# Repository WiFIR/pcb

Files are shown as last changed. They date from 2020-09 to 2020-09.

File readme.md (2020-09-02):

# WiFI*R*

The WiFI*R* is a WiFi IR blaster / remote, based around a WeMos D1 mini (ESP8266)

The WiFIR was made from a need to control a heatpump / ac to allow pre-heating of a summer-house before arriving. It can however control anything IR controlled.

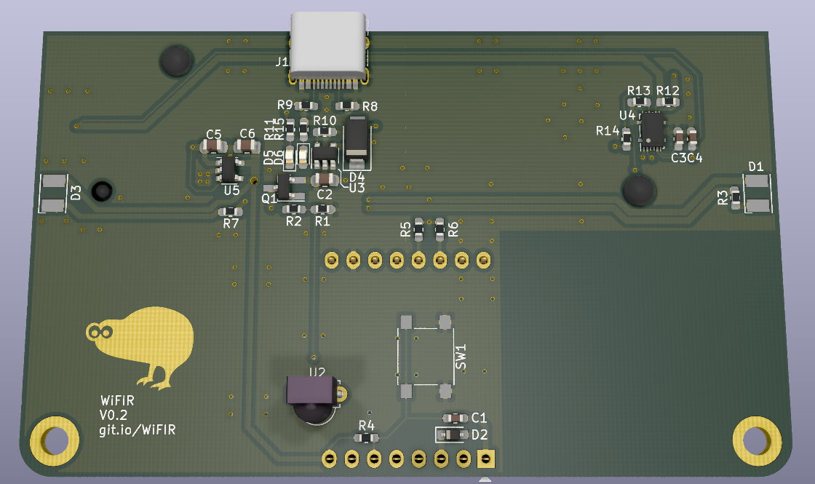
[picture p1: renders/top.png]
top render

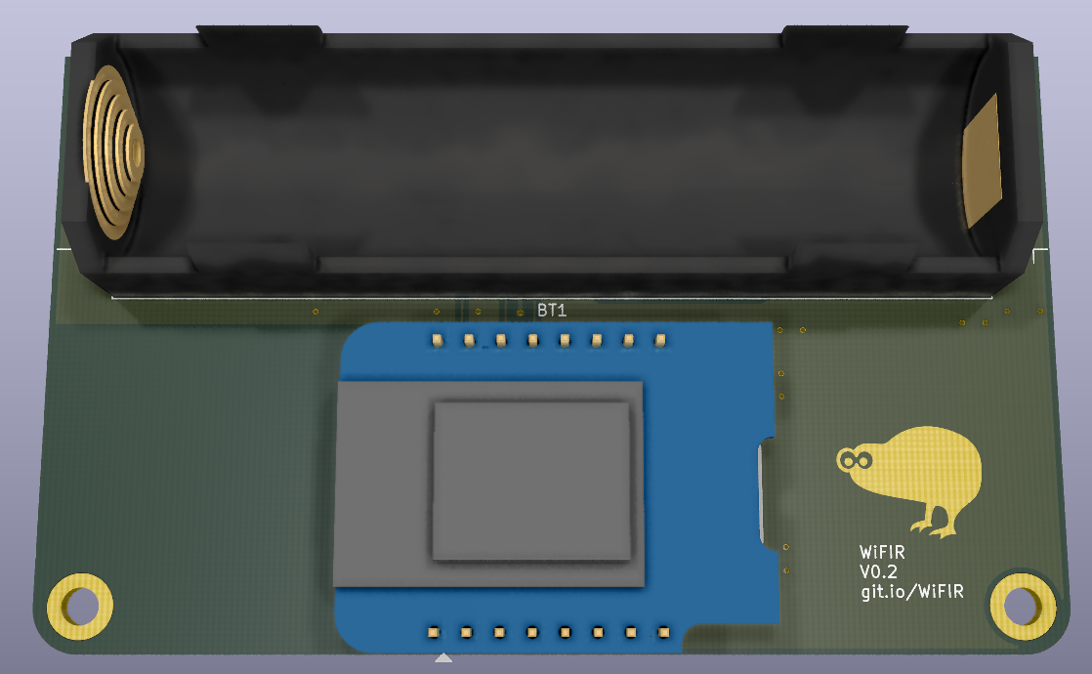
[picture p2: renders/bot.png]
bottom render


[Interactive BOM](https://WiFIR.github.io/pcb/ibom.html)

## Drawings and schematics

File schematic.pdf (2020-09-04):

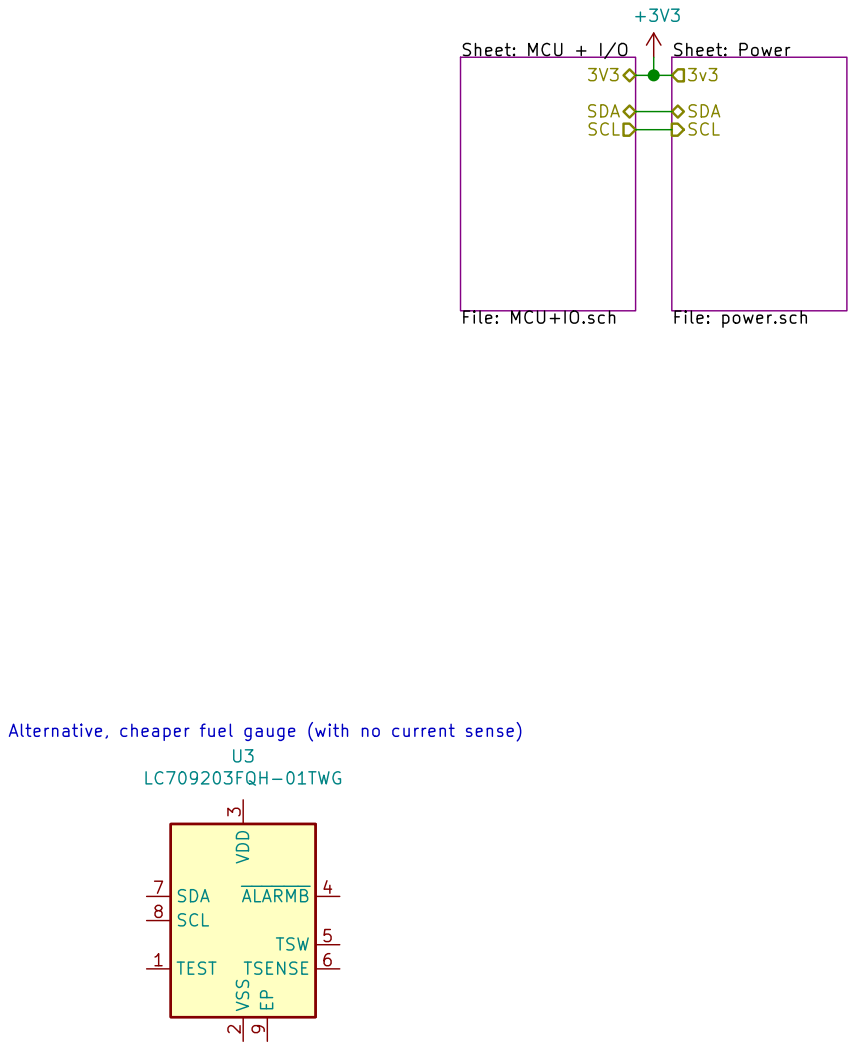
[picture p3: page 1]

+3V3 Alternative, cheaper fuel gauge (with no current sense)

Sheet: Power File: power.sch SDA

File: MCU+IO.schSCL SDA

3 ALARMB 4 TSW 5 TSENSE 6 SDA 7 SCL 8 EP

File: pcb.sch Sheet: / WiFi connected IR blaster / reciever

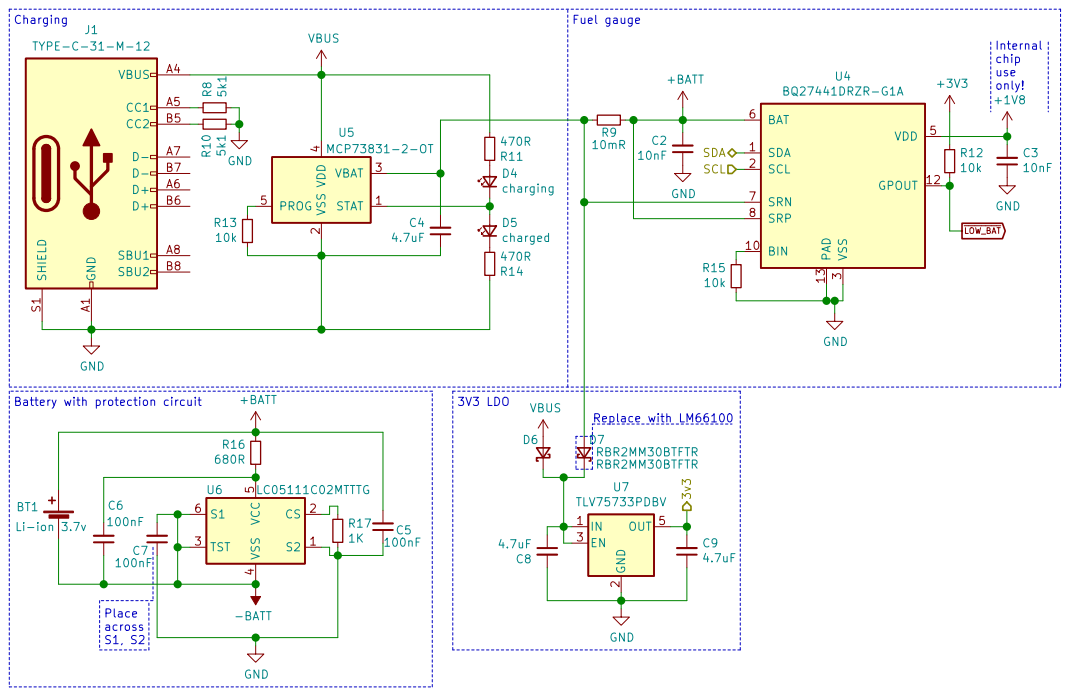
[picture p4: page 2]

Internal chip use only!

3 VDD 5 BAT 6 SRN 7 SRP 8 U4 BQ27441DRZR-G1A

Battery with protection circuit

Replace with LM66100 Place across S1, S2

File: power.sch Sheet: /Power/ WiFi connected IR blaster / reciever C7

Id: 2/3 Title: WiFIR: Battery and power management

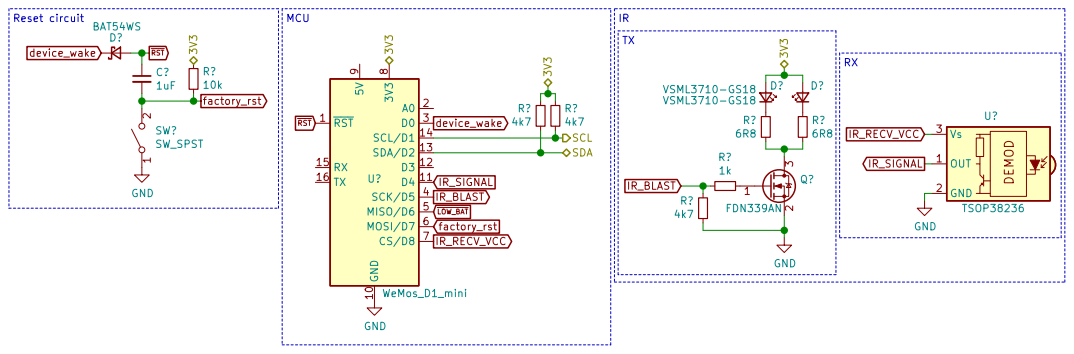
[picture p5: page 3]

factory_rst RST
10k GND
File: MCU+IO.sch Sheet: /MCU + I/O/ WiFi connected IR blaster / reciever GND

9 U? WeMos_D1_mini DEMOD OUT 1 GND 2 Vs 3 U? TSOP38236 R?

Id: 3/3 Title: WiFIR: MCU and I/O

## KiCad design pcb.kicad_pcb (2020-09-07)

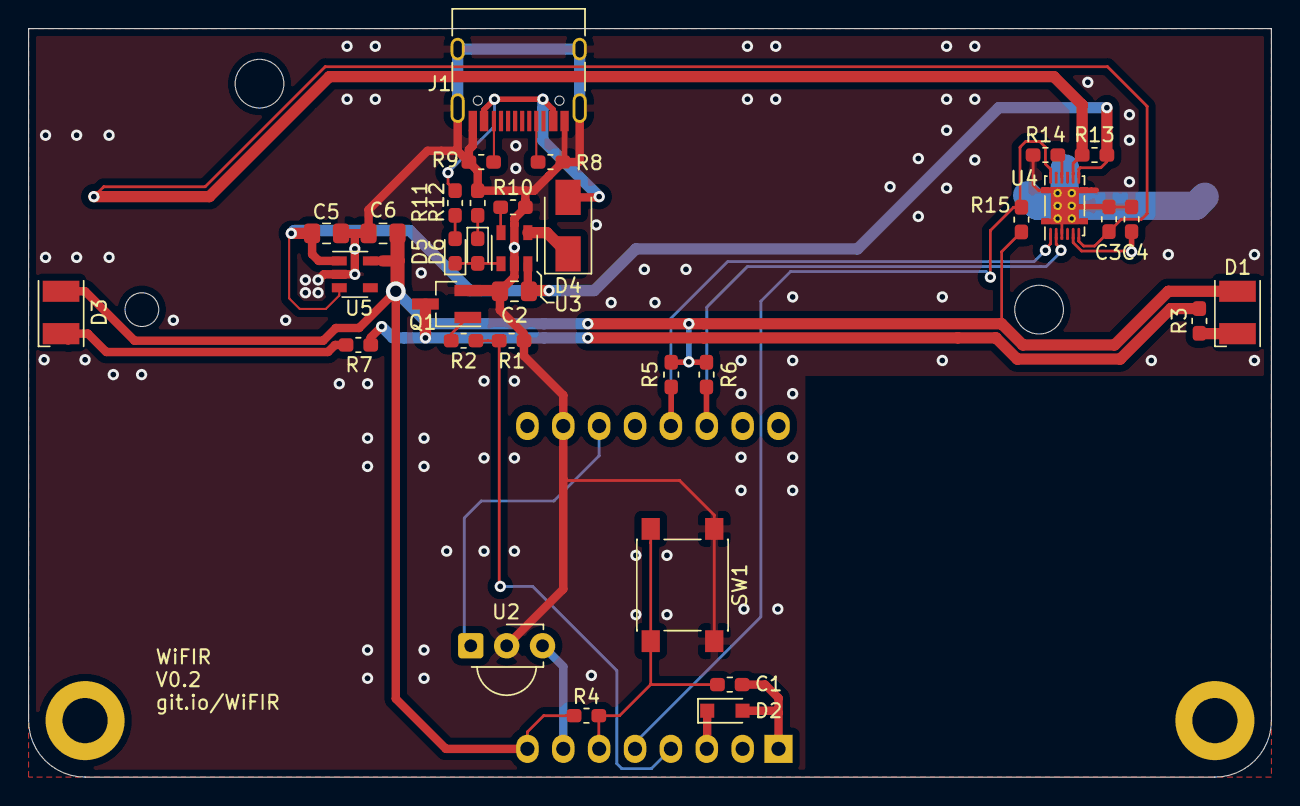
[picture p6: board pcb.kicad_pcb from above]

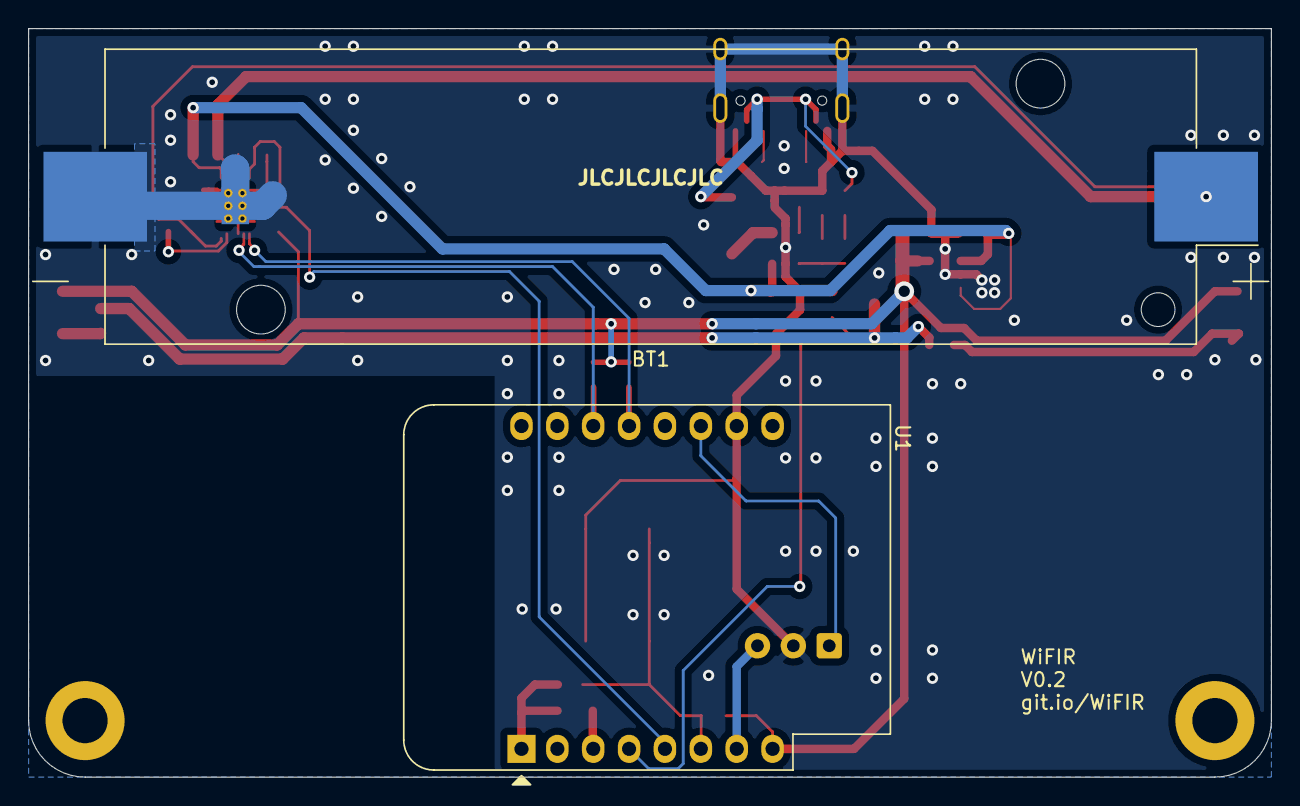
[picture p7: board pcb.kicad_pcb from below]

Board: 2 copper layers, 88.0 x 53.0 mm, 36 parts (2 on the bottom side), 27 nets.

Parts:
BT1: protected 18650; BatteryHolder_Keystone_1042_1x18650
C1: 1uF; C_0603_1608Metric_Pad1.05x0.95mm_HandSolder
C2, C5, C6: 4.7uF; C_0805_2012Metric_Pad1.15x1.40mm_HandSolder
C3, C4: 10nF; C_0603_1608Metric_Pad1.05x0.95mm_HandSolder
D1, D3: VSML3710-GS18; LED_PLCC-2
D2: BAT54WS; D_SOD-323_HandSoldering
D4: MBRA140; D_SMA
D5: charging; LED_0603_1608Metric_Pad1.05x0.95mm_HandSolder
D6: charged; LED_0603_1608Metric_Pad1.05x0.95mm_HandSolder
J1: TYPE-C-31-M-12; USB_C_Receptacle_HRO_TYPE-C-31-M-12
Q1: FDN339AN; SOT-23_Handsoldering
R1, R5, R6: 4k7; R_0603_1608Metric_Pad1.05x0.95mm_HandSolder
R2: 1k; R_0603_1608Metric_Pad1.05x0.95mm_HandSolder
R3, R7: 6R8; R_0603_1608Metric_Pad1.05x0.95mm_HandSolder
R4, R10, R14, R15: 10k; R_0603_1608Metric_Pad1.05x0.95mm_HandSolder
R8, R9: 5k1; R_0603_1608Metric_Pad1.05x0.95mm_HandSolder
R11, R12: 470R; R_0603_1608Metric_Pad1.05x0.95mm_HandSolder
R13: 10mR; R_0603_1608Metric_Pad1.05x0.95mm_HandSolder
SW1: SW_SPST; SW_Push_1P1T_NO_6x6mm_H9.5mm
U1: WeMos_D1_mini; WEMOS_D1_mini_light
U2: TSOP38236; Vishay_MINICAST-3Pin
U3: MCP73831-2-OT; SOT-23-5
U4: BQ27441DRZR-G1A; Texas_S-PDSO-N12
U5: TLV75733PDBV; SOT-23-5

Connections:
+1V8: C4.2, U4.5
+3V3: C6.2, D1.2, D3.2, R4.2, R5.2, R6.2, R15.2, U1.8, U5.5
+BATT: BT1.1, C3.2, R13.1, U4.6, U4.8
GND: BT1.2, C2.1, C3.1, C4.1, C5.2, C6.1, J1.A1, J1.A12, J1.B1, J1.B12, J1.S1, Q1.2, R1.1, R8.2, R9.1, R10.1, R12.2, R14.1, SW1.1, U1.10, U2.2, U3.2, U4.3, U4.13, U5.2
IR_BLAST: R1.2, R2.1, U1.4
IR_RECV_VCC: U1.7, U2.3
IR_SIGNAL: U1.11, U2.1
unnamed: D1.1, R3.1
unnamed: D3.1, R7.1
unnamed: D4.1, U3.4
unnamed: D5.1, D6.2, U3.1
unnamed: D5.2, R11.2
unnamed: D6.1, R12.1
unnamed: J1.A5, R8.1
unnamed: J1.B5, R9.2
unnamed: Q1.1, R2.2
unnamed: Q1.3, R3.2, R7.2
unnamed: R10.2, U3.5
unnamed: R14.2, U4.10
SCL: R6.1, U1.14, U4.2
SDA: R5.1, U1.13, U4.1
VBUS: D4.2, J1.A4, J1.A9, J1.B4, J1.B9, R11.1
VCCQ: C2.2, C5.1, R13.2, U3.3, U4.7, U5.1, U5.3
device_wake: D2.1, U1.3
factory_rst: C1.2, R4.1, SW1.2, U1.6
~LOW_BAT: R15.1, U1.5, U4.12
~RST: C1.1, D2.2, U1.1

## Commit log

2020-09-02 Tested working hardware.
    [pcb.kicad_pcb, pcb.sch]
2020-09-04 Implemented on-board cell protection to allow the use of un-protected cells
    [MCU+IO.sch, pcb.sch, power.sch]
2020-09-04 Updated s pdf schematic
    [MCU+IO.sch]
2020-09-04 Updated schematic info
    [MCU+IO.sch, pcb.sch, power.sch]
2020-09-04 Actually push schematic
2020-09-07 Did stuff
    [MCU+IO.sch, pcb.kicad_pcb, pcb.sch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]
